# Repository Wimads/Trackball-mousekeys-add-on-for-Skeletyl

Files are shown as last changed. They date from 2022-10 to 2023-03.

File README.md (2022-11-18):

# Trackball and mousekey add-on for Bastardkb Skeletyl

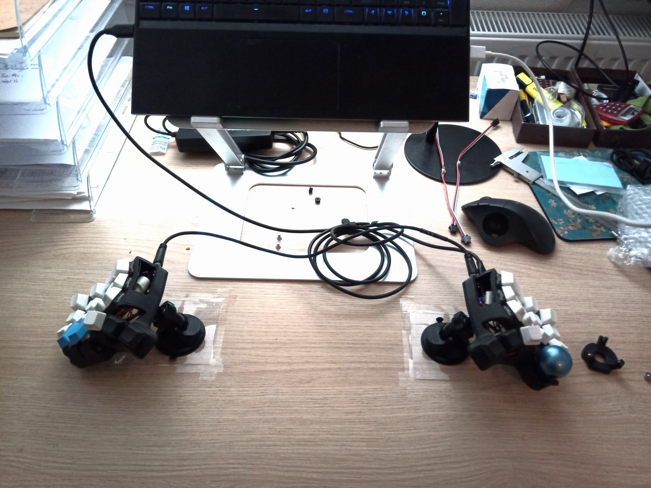
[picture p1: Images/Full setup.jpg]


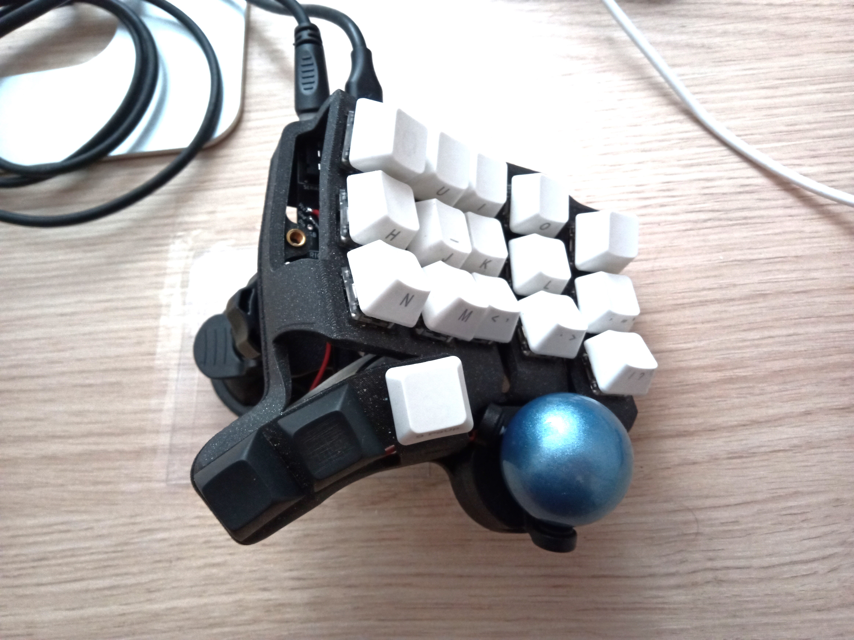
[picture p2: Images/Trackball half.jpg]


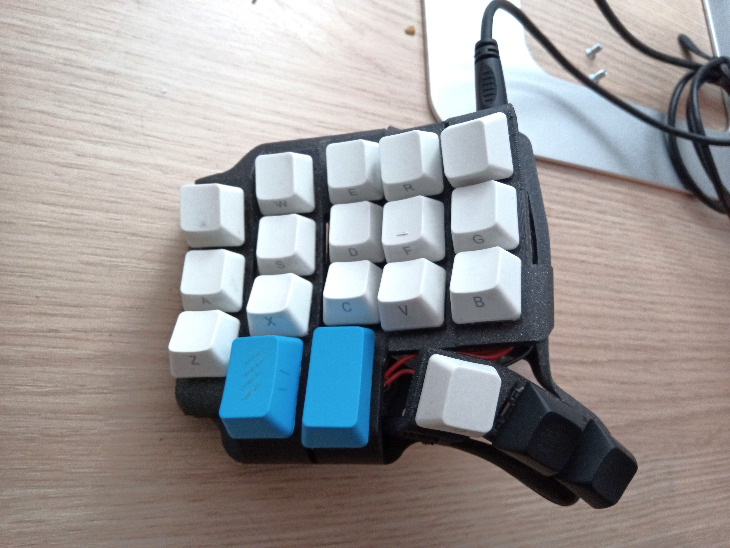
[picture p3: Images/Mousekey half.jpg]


This add-on is designed around the following components:
* Unmodified Skeletyl_v3v7 case (compatibility with earlier or newer versions of the case has not been tested). Bastardkb github repository: https://github.com/Bastardkb/Skeletyl/tree/main/archive/V3
* The mousekey plate is designed for MX switches.
* Requires 2 diodes for the mousekey plate.
* Trackball plate is designed for a 34mm trackball (like the one in a logitech M575)
* Tindie PWM3360 sensor pcb (for its compact size as compared to the charybdis sensor pcb)
* 2x M3x5x5 heated screw inserts (for mounting the trackball holder to the plate) (make sure you print in a material that can take heated screw inserts)
* 2x M3x10 countersunk screws (for mounting the trackball holder to the plate)
* There is 3 options for bearings:
  * Roller bearings (MR63-3x6x2.5mm), with 3x M3x8 set screws to mount them.
  * BTU bearings (Veichu VCN310, 7.5mm)
  * Static bearings (3mm ZrO2 or Si3N4 balls)
  


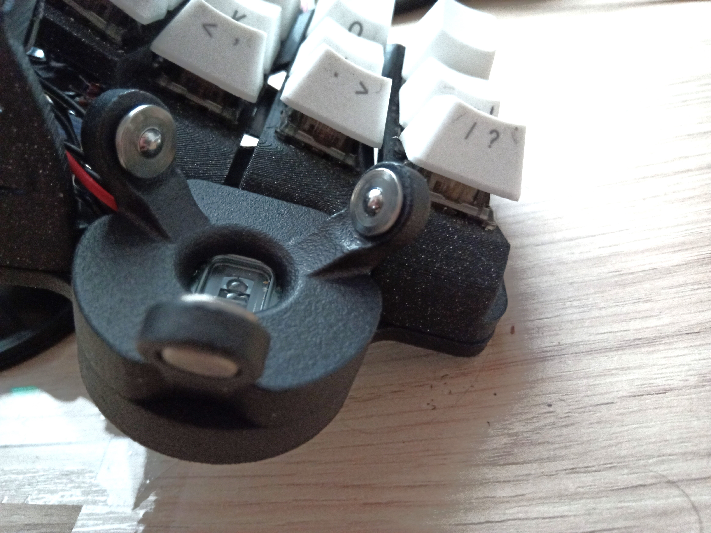
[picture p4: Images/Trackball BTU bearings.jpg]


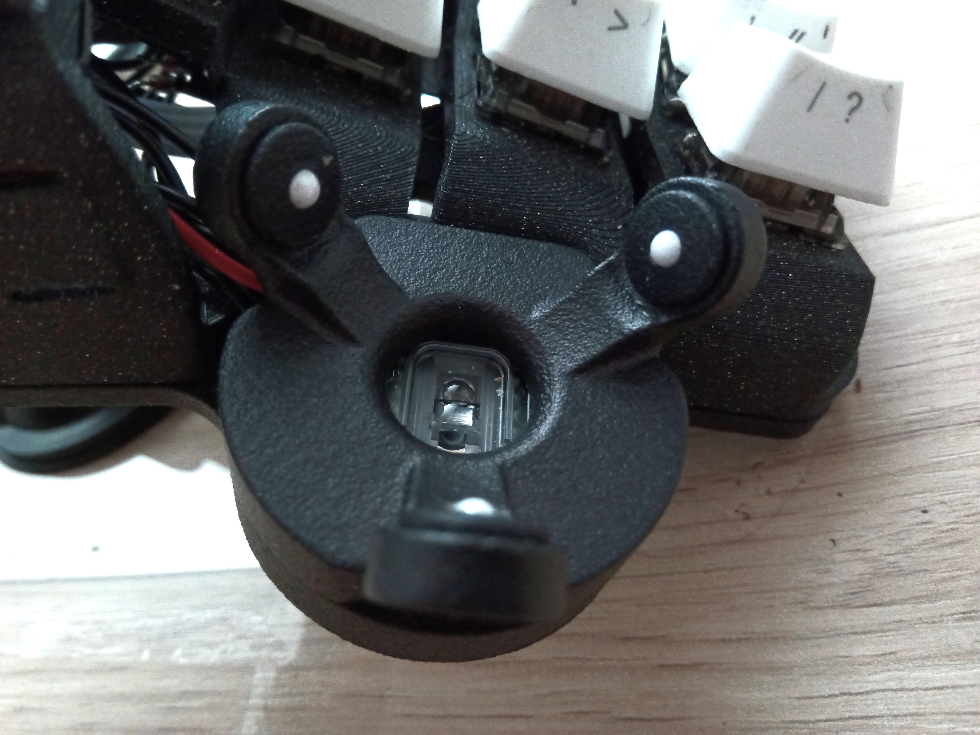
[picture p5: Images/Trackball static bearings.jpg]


Source 3D files in OnShape: 
https://cad.onshape.com/documents/c7d31654920783cf2170d04f/w/e26ac92a8d6e84ba2575ffdb/e/2fa55001fc01750eb4b64711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

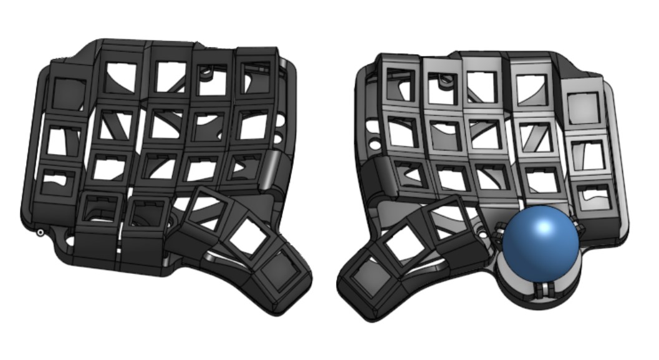
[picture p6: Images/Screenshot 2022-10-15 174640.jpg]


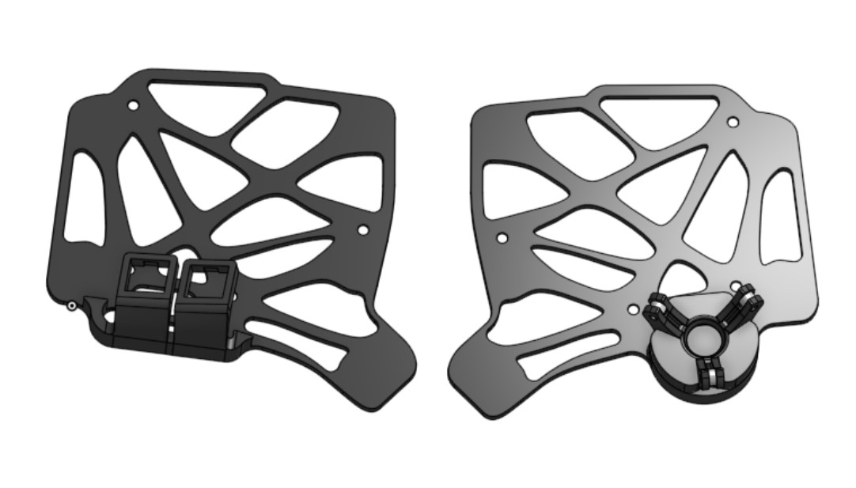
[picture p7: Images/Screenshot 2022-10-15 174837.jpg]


**How is this different from a Charybdis?**

1. This is meant to be an add-on for an existing skeletyl build (ie, you already built a skeletyl, and decided you want a trackball as well). It doesn't require a modified case, so you don't have to build an entirely new board and trash your skeletyl. You can simply add it to your existing skeletyl. 
2. The ball position is slightly different, and intended to be used by your middle finger/ring finger, instead of the thumb.
3. It doesn't sacrifice a thumb key on the trackball side.
4. For the other keyboard half there is an add-on for 2 mouse keys, so you don't have to mess around with layers to use the mouse.

**Wiring trackball and mousekeys**

How to wire up the trackball sensor and the mousekeys will depend on your existing skeletyl build. Below are instructions for a Skeletyl V3, with the v1 Elite-c shield; if your setup is different, your wiring (and thus your firmware) will be different as well.

*Trackball sensor*

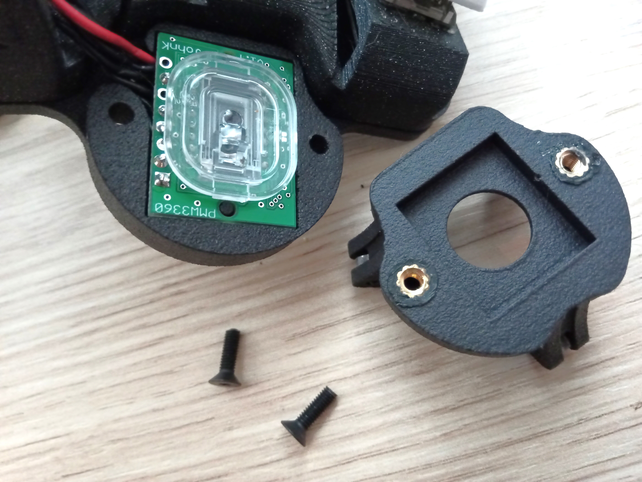
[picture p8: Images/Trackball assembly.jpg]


The trackball requires to use the MOSI, MISO and SCK pins of the elite-c, which are B1, B2 and B3. If you followed the build guide by bastardkb for v1 Elite-c shield, you will notice that these pins are already used by the key matrix, for column 4, 5 and 6. So you will need to rewire those columns. I have wired them as follows (if you want to use my firmware as a template, use these same pins):
* Column 4: F1 (was B1)
* Column 5: C7 (was B3)
* Column 6: D5 (was B2)
* Trackball MO: B2 (MOSI)
* Trackball MI: B3 (MISO)
* Trackball SC: B1 (SCLK)
* Trackball SS: F0
* Trackball GD: GND (any)
* Trackball VI: VCC

*Mousekeys*

I wired the mousekeys to the same row as the thumb cluster. The 3 thumb keys occupy C2R4, C4R4, C5R4; the mouse keys will be wired to C3R4, and C6R4. The columns require a diode, with the black line facing away from the switch.

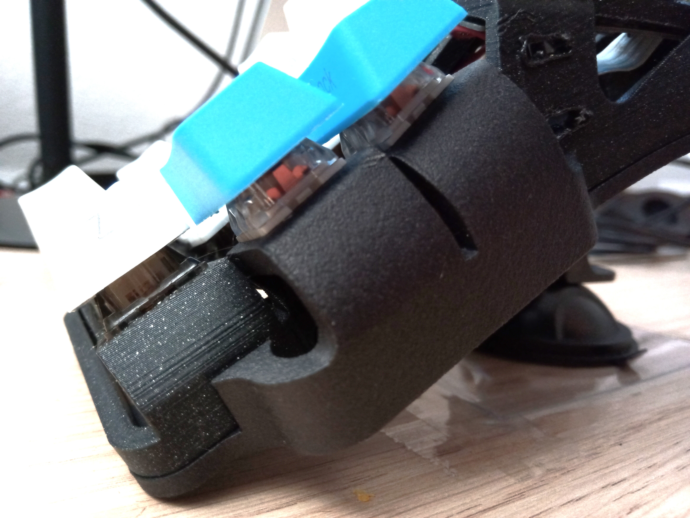
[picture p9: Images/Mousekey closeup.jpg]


**Firmware**

The basis for the firmware is the firmware for the bastardkb Charybdis
* To use this firmware, fork from qmk mainstream (https://github.com/qmk/qmk_firmware)
* Add your own keymap folder in keyboards/bastardkb/charybdis/3x5/keymaps/\[my keymap folder]
* Copy the firmware files from this repository into your keymap folder
* If your wiring is identical to mine, you are now good to go.
* For compiling the firmware: qmk compile -kb bastardkb/charybdis/3x5/v1/elitec -km \[my keymap folder]
* If your trackball side wiring is different than mine, you will need to adapt the config.h file accordingly
* If you didn't add the mousekeys, or wired them differently, you will also need to adapt the LAYOUT definition in the keymap.c file
* If you use a different MCU (not elite-c), you may need to adapt the rules.mk file as well.

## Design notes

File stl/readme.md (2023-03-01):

**notes on stl files**

These files were designed to be printed using MJF. SLS should also work.
If you want to print in FDM, I recommend removing the cutouts for the rubber bumpers on the bottom of the plates, since adding support may not be a very convenient solution here.
To edit these files, I recommend using the source file in OnShape: 
https://cad.onshape.com/documents/c7d31654920783cf2170d04f/w/e26ac92a8d6e84ba2575ffdb/e/2fa55001fc01750eb4b64711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

Files to print:
* For mouse keys: mousekey-plate_v221018
* For trackball: trackball-plate_v221027
* There is 3 options for trackball bearings, which require different files to print for the trackball holder:
  * Option 1: For roller bearings (MR63-3x6x2.5mm), print trackball-holder_v221027
  * Option 2: For BTU bearings (Veichu VCN310, 7.5mm), print trackball-holder-v2_v221116
  * Option 3: For static ceramic bearings (3mm ZrO2 or Si3N4 balls), print trackball-holder-v2_221116 AND:
    * (recommended) Static-bearing-holder_2.1_v230216.stl - latest version - which has the 3 bearing holders connected with a ring, which helps to prevent accidentally knocking the ball out of its socket, and may also help preventing any alignment issues due to printing tolerances.
    * (old version) 3x Static-bearing-holder_v221117.stl - old version - 3 separate bearing holders, basically a dimensional copy of the 7.5mm Veichu VCN310 BTU's. Not recommended for this design, but may still be useful if you are working on any other project that was designed for these BTU's.

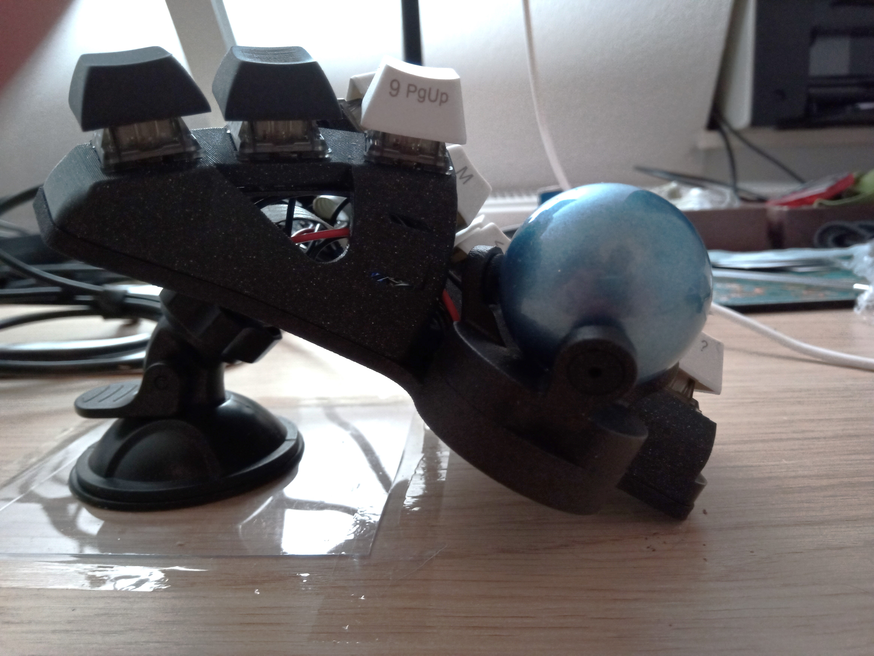
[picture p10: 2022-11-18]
Images/Trackball side view.jpg

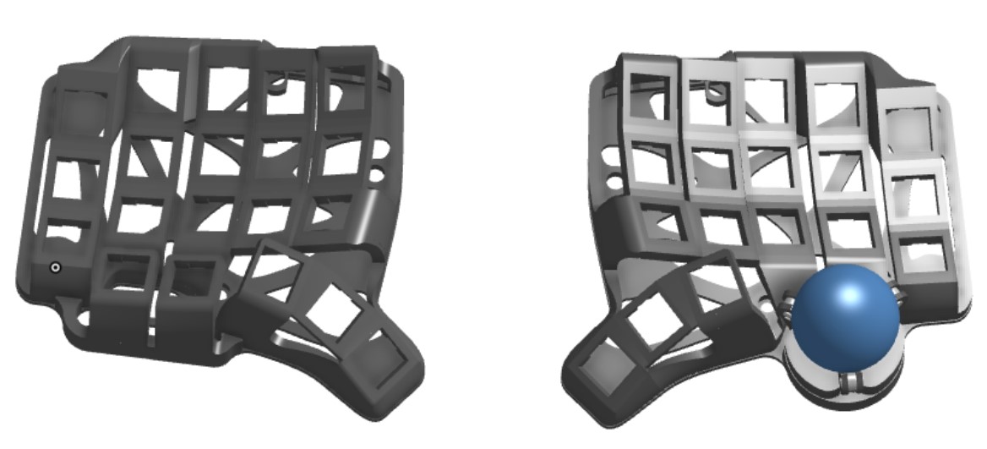
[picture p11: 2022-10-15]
Screenshot 2022-10-15 174640.jpg

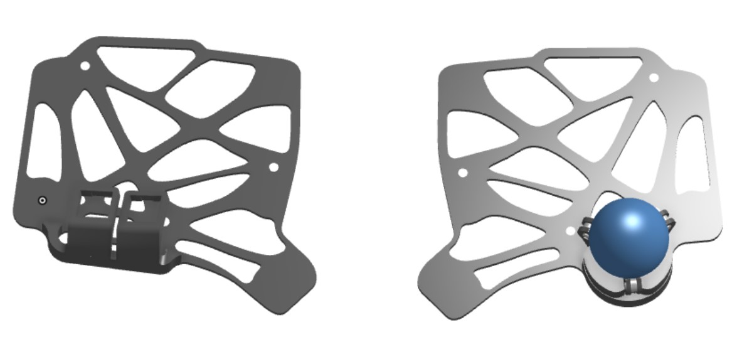
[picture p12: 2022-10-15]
Screenshot 2022-10-15 174837.jpg

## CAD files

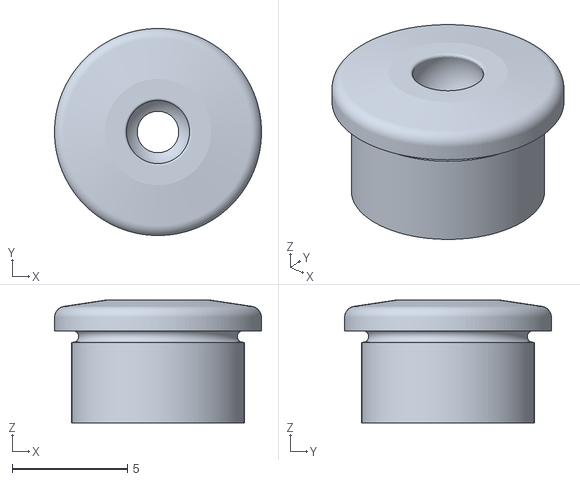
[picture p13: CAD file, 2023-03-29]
stl/Static-bearing-holder_v221117.stl
9.00 x 9.00 x 5.33

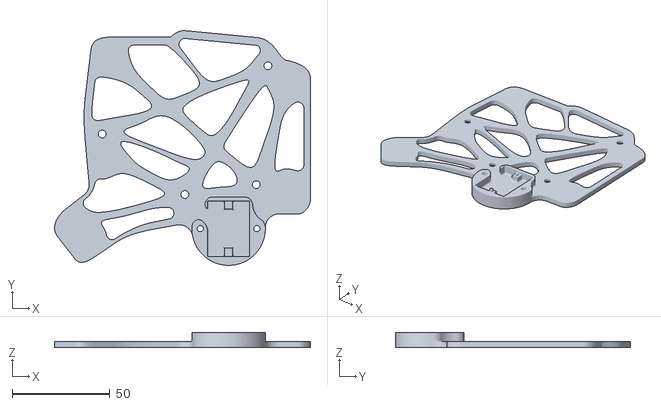
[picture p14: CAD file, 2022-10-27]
stl/Trackball-plate_v221027.stl
131.3 x 120.4 x 7.79

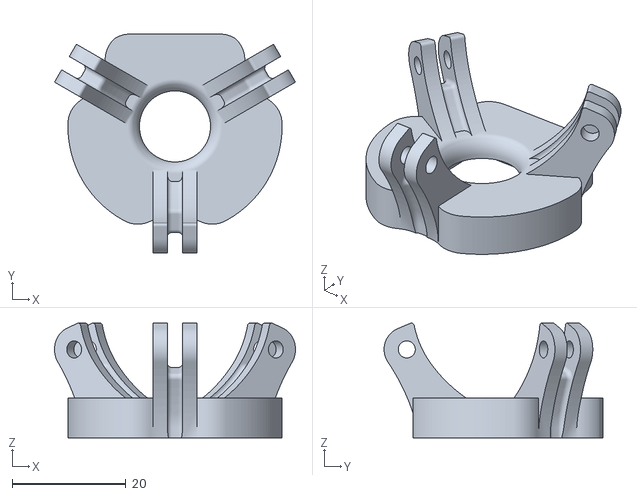
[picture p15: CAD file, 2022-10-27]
stl/Trackball-holder_v221027.stl
42.4 x 38.5 x 20.2

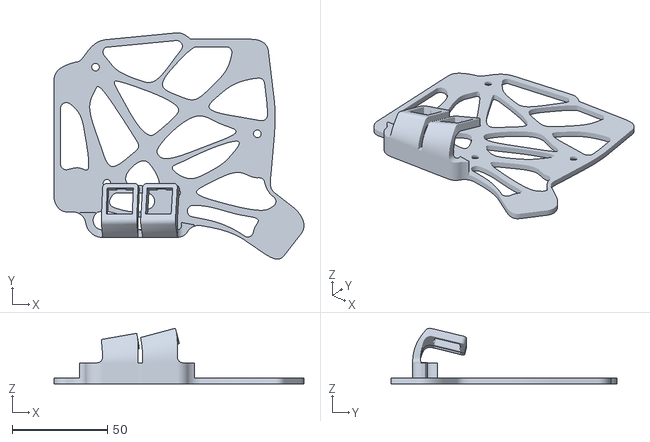
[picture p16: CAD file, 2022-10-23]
stl/Mousekey-plate_v221018.stl
131.3 x 118.8 x 29.1

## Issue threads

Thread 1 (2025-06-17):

[Question] 3D Printing

5andr0, 2025-06-17:
Hi,

thanks for sharing your trackball device.
How did you print the trackball holder? In the pictures the surface looks super smooth on the holder compared to the layered keyboard print.
Did regular FDM prints break with pressure on the ball?

Thanks

Wimads, 2025-06-17:
Hi @5andr0 ,

Its an MJF print, ordered from JLCPCB.

I do not have my own FDM printer, and don't have a lot of experience with that either, so I can't really advice you on FDM printing it.

However, I know of at least one person who has successfully printed it on a regular FDM printer, with some clever support settings for the top half. So it is possible, no problems with strength either.

Closed 2025-06-17.

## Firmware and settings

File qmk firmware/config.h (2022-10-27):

/**
 * Copyright 2021 Charly Delay <charly@codesink.dev> (@0xcharly)
 *
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
 * You should have received a copy of the GNU General Public License
 * along with this program.  If not, see <http://www.gnu.org/licenses/>.
 */
#pragma once

/* Trackball configuration */
//undefine charybdis trackball configuration
#undef ROTATIONAL_TRANSFORM_ANGLE
#undef POINTING_DEVICE_INVERT_X
//define Wimads trackball configuration
#define CHARYBDIS_DRAGSCROLL_REVERSE_Y
#define CHARYBDIS_MINIMUM_SNIPING_DPI 200
#define CHARYBDIS_MINIMUM_DEFAULT_DPI 350
#define POINTING_DEVICE_INVERT_Y

/* Elite-c pinout configuration */
//undefine charybdis pinout configuration
#undef MATRIX_ROW_PINS
#undef MATRIX_COL_PINS
#undef MATRIX_ROW_PINS_RIGHT
#undef MATRIX_COL_PINS_RIGHT
#undef SOFT_SERIAL_PIN
#undef PMW33XX_CS_PIN
//define Wimads pinout configuration (modified based on skeletyl with v1 elite-c shield)
#define MATRIX_ROW_PINS       { B5, F7, F6, B6 } 
#define MATRIX_COL_PINS       { E6, C6, B1, B3, B2 }
#define MATRIX_ROW_PINS_RIGHT { B5, F7, F6, B6 }
#define MATRIX_COL_PINS_RIGHT { E6, C6, F1, C7, D5 } //rewired from B1, B3, B2
#define SOFT_SERIAL_PIN D0
#define PMW33XX_CS_PIN F0

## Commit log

2022-10-15 Uploaded STL files
    [Mousekey-plate_v221015.stl, Trackball-holder_v221015.stl, Trackball-plate_v221015.stl]
2022-10-23 Revised stl files
    [Mousekey-plate_v221015.stl, Mousekey-plate_v221018.stl, Trackball-holder_v221015.stl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]
2023-03-01 Improved static bearing holder, new instructions
2023-03-29 fix orientation of model
    [Static-bearing-holder_v221117.stl]

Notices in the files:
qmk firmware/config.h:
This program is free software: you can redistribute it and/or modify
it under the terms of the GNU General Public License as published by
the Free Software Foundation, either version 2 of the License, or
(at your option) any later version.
